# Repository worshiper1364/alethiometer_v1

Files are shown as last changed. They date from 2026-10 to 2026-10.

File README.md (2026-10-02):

# Lyra's Alethiometer

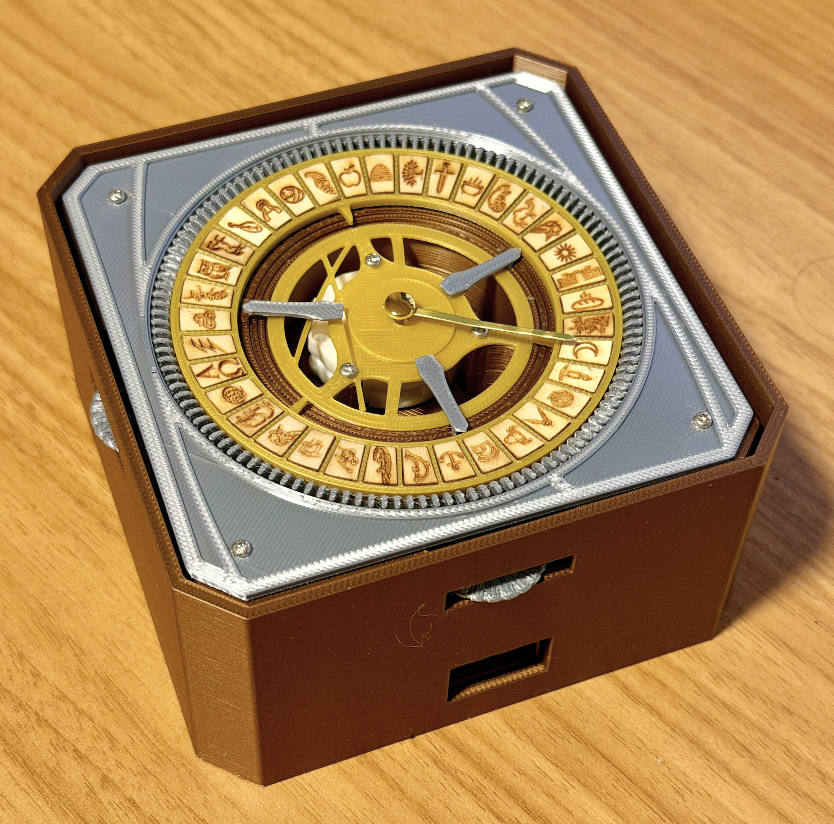
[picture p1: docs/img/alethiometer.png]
Finished alethiometer
 

https://github.com/user-attachments/assets/59460df4-214a-49e5-ad2c-306fc8ed92e8

An alethiometer is a divination device from the book series _His Dark Materials_ by Philip Pullman. This version is based on the one in [this YouTube video](https://www.youtube.com/watch?v=rpL9xWBeznU) which was created by Jamie of [Myth Made](https://www.youtube.com/@themythmade). That replica was in turn based on the prop from the BBC TV show adaptation of _His Dark Materials_.

This is an unofficial fan project and a collection of files intended to help others build an alethiometer. It is not super organized. Although I cannot guarantee any help, feel free to post questions in [r/AlethiometerBuild](https://www.reddit.com/r/AlethiometerBuild/)

## Sections
I've organized roughly by fabrication method

* [Electronics](electronics/)
* [Laser cutting](laser_cutting/)
* [3D printing](3d_printing/)

## Broad Assembly Steps

1. Print all the 3D printed parts
2. Laser engrave and cut all the symbol tiles and place them into the symbol holder
2. Drill existing holes on the motor plate to the right size
3. Drill the axle holes of the gears wider
3. With a soldering iron, install the heat set threaded inserts
2. Solder jumper wires to motor pins
3. Connect/solder wires to touch sensor module
2. Mount Nano to half size breadboard
3. Upload the Adruino sketch onto the Nano
4. Highly recommend wiring motor and touch sensor to the breadboard and testing it works before proceeding
3. Place motor plate support wall in the lower case, making sure windows line up
4. Stick the breadboard with Nano onto the floor of the case, aligning USB port with the window away from the hand dials
5. Stick the touch sensor module through the window that is on the same side as one of the hand dials, then wire up to breadboard
6. Carefully mount the motor onto the center of the motor plate, making sure the wires go through the rectangular cutouts and the motor pegs line up with the holes in the plate
7. Place the motor plate part way into the case, making sure the hand dial cutouts line up with the slots on the case. While holding, wire up the motor to the breadboard
8. Place the motor plate on top of the motor plate stand
9. Install the inner plate into the center
10. Stack the inner gears and place them around the inner ring of the motor plate
11. Install the gears, using M3 screws
12. Place the outer silver ring thing into the center of the motor plate, lining up the ledges
13. Place the symbol holder with tiles on top of the outer silver ring thing
14. Mount the outer dial face
15. Press the clock hand onto the shaft.
16. Centre the hand on the middle of a symbol
17. Plug in USB and touch the sensor.

## Misc Notes
* This project is provided as-is, without warranty of any kind. Use it at your own risk; I accept no liability for any damage or injury resulting from its use.
* This is an unofficial personal fan project, and not affiliated with the BBC, Philip Pullman, or Myth Made
* Ventilate when soldering, heat-set tips are hot, never leave the laser unattended, and small parts are unsuitable for young kids
* This build lacks a lid and is significantly taller than Jamie's version or the BBC version in order to accommodate the electronics I was able to use. The next version I intend to make it closer to the original size, and with a lid
* Due to lack of skills and access, metal parts were substituted with 3D printed parts

## Acknowledgements
* This project would not be possible without the [Myth Made alethiometer](https://www.youtube.com/watch?v=rpL9xWBeznU) built by Jamie, who made the plans publicly available [here](https://mythmade.gumroad.com/l/trhgos). They are available for free, but please consider chipping in what you can afford like I did to support her wonderful work!
* Claude by Anthropic and ChatGPT by OpenAI were generative AI tools used for tutoring, bouncing ideas around, reviewing, and generating code. All output was reviewed by me and tested on the hardware described here.

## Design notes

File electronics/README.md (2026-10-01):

# Alethiometer Electronics

The electronics and Arduino code for the divination needle of a working alethiometer replica from His Dark Materials, based on Myth Made's [YouTube build](https://www.youtube.com/watch?v=rpL9xWBeznU). The Arduino sketch (code) is adapted from Myth Made's original code. Touch the sensor and the needle swings to a random sequence of symbols, pausing and sometimes quivering on each one.

## Folder layout

```
electronics/
├── README.md                        this file: usage, wiring and theory
└── arduino_alethiometer/
    └── arduino_alethiometer.ino     the Arduino sketch
```

The `.ino` file is the Arduino code file and can be opened with any text editor. The Arduino IDE needs the sketch folder and the `.ino` file to share a name, so keep `arduino_alethiometer/arduino_alethiometer.ino` together. No extra libraries are needed.

## Hardware

### Supplies

| Part | Description | Example Link |
| --- | --- | --- |
| Breadboard (half size) | Needs to fit in the case | [Breadboard and Jumper Wire Bundle](https://www.amazon.com/BOJACK-Values-Solderless-Breadboard-Flexible/dp/B08Y59P6D1) |
| Jumper wires (male to male)| One end is stripped and soldered to the motor pins, the other plugged into the breadboard. | Included in above |
|Dupont jumper wires (male to female)| If the sensor module has headers already attached, you may not need to solder and can use these to connect to the header pins|[40 pack wires](https://www.amazon.com/SinLoon-Breadboard-Arduino-Circuit-40-Pack/dp/B08M3QLL3Q)|
| Arduino Nano microcontroller board | I used a Nano clone, not an original Arduino Nano. Mine had headers already soldered in. You will need to follow the [Elegoo instructions](https://www.elegoo.com/blogs/arduino-projects/elegoo-arduino-nano-board-ch340-usb-driver) to install the right driver on your computer for the Arduino IDE to work with it. | [Elegoo Presoldered Nano Board USB-C](https://www.amazon.com/ELEGOO-Presoldered-Compatible-Arduino-Microcontroller/dp/B0F6Y7GS4Q) |
| Motor | X27.168 automotive gauge stepper motor. For 360° movement, you will need to open the motor and cut off the small bump on the big gear that acts as an end stop. I used a razor blade to cut and scrape, and followed up with a file. Open it carefully: the parts can spring out and are easy to lose. I highly advise taking photos as you open it up and take things out, so you can reconstruct | [Adafruit x27.168 stepper motor](https://www.adafruit.com/product/2424) |
| Touch sensor | HiLetgo TTP223B capacitive touch sensor module, default momentary mode. The mode matters for the code to work; on some modules you can change it by bridging solder pads. | [HiLetgo TTP223B capacitive touch sensor module](https://www.amazon.com/HiLetgo-TTP223B-Capacitive-Digital-Raspberry/dp/B00HFQEFWQ) |
|Clock hand| For final assembly, I used a brass colored clock hand with a hub that fit through the inner plate hole and onto the motor shaft. None of the clock hands had the right length, so I used a wirecutter to cut down to length and make a point|[Paraor Set of 20 clock hands](https://www.amazon.com/dp/B0CQ2FL2MS)|

#### Notes
* You could skip the breadboard completely by soldering wires directly from the Nano to the motor and touch sensor.
* For the Elegoo Nano board, use the cable that came with it for best results. USB-C to USB-C cables didn't work for me; only USB-A to USB-C did. (Many budget USB-C boards leave out the resistors that tell a USB-C port to supply power.) I ended up connecting: computer USB-C port -> USB-C to USB-A adapter -> USB-A end of cable -> USB-C end of cable -> Nano USB-C port.
* The motor is driven directly from the Nano's pins, with no driver chip. That's fine for the X27.168, which draws roughly 20 mA per coil at 5 V. If you substitute a different gauge motor or a 3.3 V board, check its datasheet first; a motor that draws more current needs a driver chip.
* In the Arduino IDE, choose Tools > Board > Arduino Nano. If uploading to a clone fails with a "not responding" error, set Tools > Processor to "ATmega328P (Old Bootloader)".

## Pre-build Testing

1. Wire up the Arduino Nano board, x27.168 motor and touch sensor on a half-sized breadboard, as in the wiring section below. I recommend placing the Nano with its USB connector right at the edge of the breadboard, since it will eventually need to sit right against a box wall.
2. Put the supplied pointer or a piece of tape on the motor shaft, so you can see the movement.
3. Connect the Nano to your computer.
4. Open `arduino_alethiometer/arduino_alethiometer.ino` in the Arduino IDE, select the Nano board and port, and upload.
5. Touch the sensor. The needle performs a reading, and the motor coils switch off when it finishes.

## Using it

Once the dial is fitted, rest the needle on the center of any symbol before powering on. Every move is a whole number of symbols (20 motor steps each), so if the needle starts centered and the motor completes every step, every stop lands on a symbol center. Nothing checks the needle's actual position, so a skipped step, a knock or a needle slipping on its shaft will throw it off until you re-center it.

When the coils first switch on, the needle may shift slightly, up to about 1°, as the motor settles into its first step position. That's normal, and nudging it back won't stick, because the motor pulls it back to the same spot next time.

If the needle gets bumped off-center, nudge it back onto the middle of a symbol before the next reading. Turn it slowly and gently: the motor datasheet warns that knocks or sudden spins of the pointer can damage its internal gears.

## Wiring

Looking down on the motor with the shaft to the north:

| From | To Arduino Pin | Note |
| --- | --- | --- |
| Motor NE pin | D4 | one coil |
| Motor SE pin | D5 | same coil as NE |
| Motor NW pin | D6 | the other coil |
| Motor SW pin | D7 | same coil as NW |
| Touch Sensor SIG | D2 | HIGH while touched |
| Touch Sensor VCC | 5V | |
| Touch Sensor GND | GND | |

The only hard rule is that each coil's two pins go to D4/D5 or to D6/D7. Swapping the two wires within one pair just reverses the direction of rotation.

## The touch sensor

The touch sensor measures the electrical capacitance of the pad. When your finger touches the pad, the capacitance increases, and when it rises past a threshold, the sensor switches its output HIGH. When you lift your finger, the output goes back to LOW. (The TTP223B can also be set to a toggle mode, where each touch flips the output and it stays that way, but this project uses the default momentary mode.) That HIGH signal goes to the Nano. The code on the Nano runs in a loop, and if it sees the HIGH signal on any pass through the loop, it starts the needle moving.

## How the Nano drives the motor

Very simplified, the motor has a small permanent magnet and two electromagnets. The permanent magnet spins the motor shaft through a series of gears. The Arduino code directs the Nano to set four pins high or low in a repeating pattern that flips the direction of current in the electromagnets. Each flip turns their combined magnetic field a quarter turn; the permanent magnet follows it like a compass, turning the gear train, and thus the needle.

## Serial Monitor bench tools

Optional, for testing with the Nano plugged into a computer. In the Arduino IDE open Tools, then Serial Monitor, set 115200 baud and the line ending to Newline, type a letter and press Enter. Opening the Serial Monitor resets the Nano, so you'll see the startup message.

| Command | What it does |
| --- | --- |
| `r` | Run a reading, same as touching the sensor |
| `t` | Tile tour: a full turn, one tile at a time. Every stop should be centered and it should finish where it started |
| `s` | Spin test: 3 turns one way, 3 back. It should land where it started; if not, look for skipped steps, rubbing or a slipping needle |
| `b` | Backlash test: steps backwards slowly so you can estimate the gear slack. Set `BACKLASH_STEPS` in the sketch to the step number where the needle first visibly moves (erring a step high is safe) |
| `x` | Switch the coils off |
| `?` | Show the command list |

Start `t`, `s` and `b` with the needle centered on a symbol.

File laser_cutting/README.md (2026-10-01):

# Laser Cutting

Symbol tiles were engraved on and cut out of 1/16" thick basswood using an Epilog Mini 40W CO2 laser cutter. I ended up using these settings, but you will need to test your own. Never leave a laser cutter unattended.

**Engrave**

* Speed: 70% speed
* Power: 95% power

**Cut**

* Speed: 48% speed
* Power: 98% power

The tiles fit perfectly into the symbol holder pockets, so I didn't need to use any glue. They are very hard to take out.

**`alethiometer_tiles_bold_and_standard.svg`**: This file contains two sets of symbols, one in bold and one not bold

**`alethiometer_tiles_material_test_subset.svg`**: This file contains a subset of symbols for testing

The symbols were generated with ChatGPT using written descriptions of the symbols.

## Symbol Order

Some places to find the order of symbols

* [V&A Museum Online Collection](https://collections.vam.ac.uk/item/O1779677/the-alethiometer-property-collins-joel/):  Nice high resolution photos of the alethiometer from the BBC show
* [HDM Wiki](https://hisdarkmaterials.fandom.com/wiki/Alethiometer)
* [Myth Made YouTube video](https://www.youtube.com/watch?v=rpL9xWBeznU)

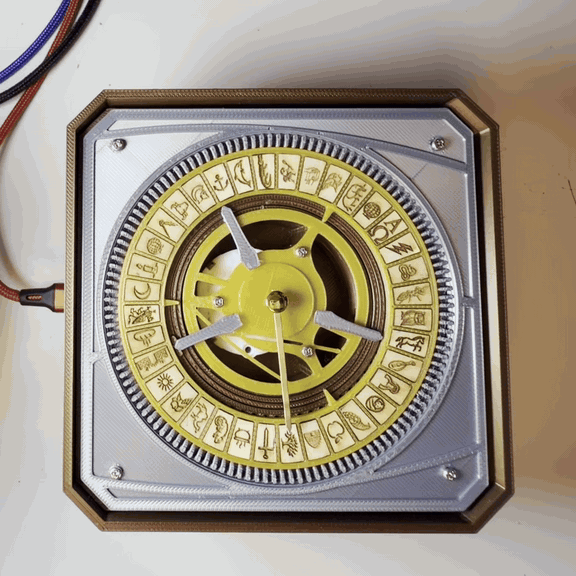
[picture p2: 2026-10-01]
docs/img/alethiometer_movement.gif

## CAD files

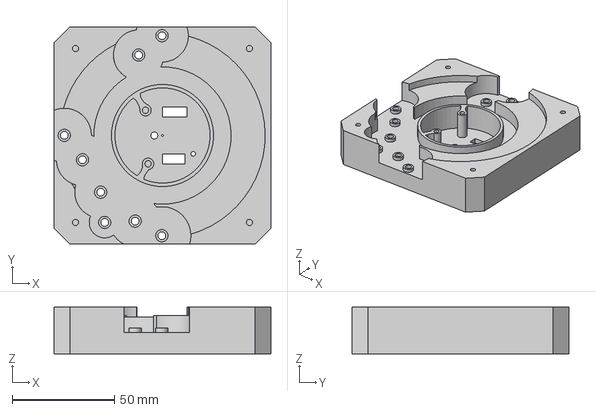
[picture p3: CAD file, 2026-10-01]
3d_printing/Motor Plate.step
105.9 x 105.9 x 22.8 mm

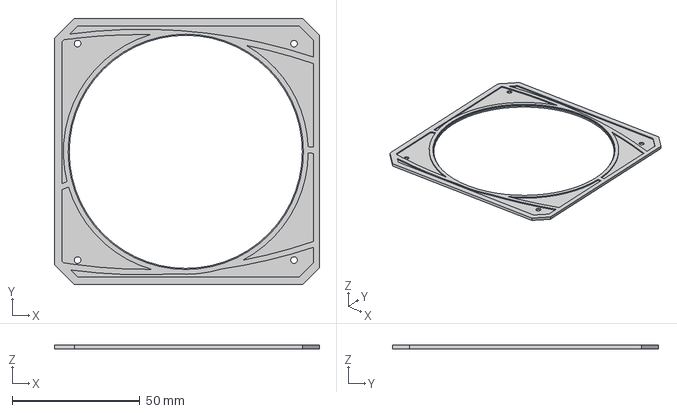
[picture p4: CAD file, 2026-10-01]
3d_printing/Outer Dial Face.step
103.9 x 104.3 x 1.40 mm

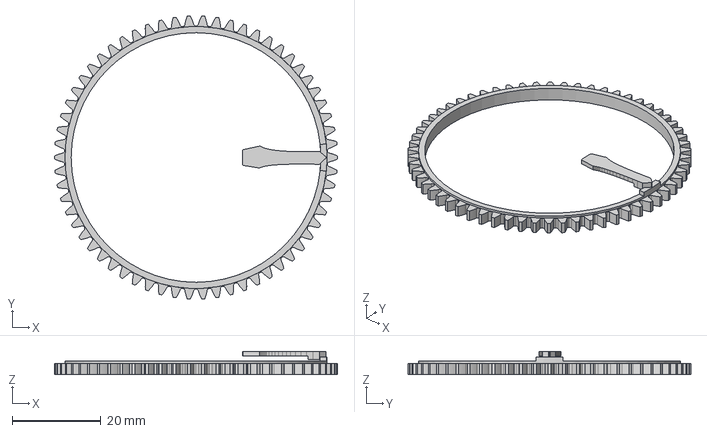
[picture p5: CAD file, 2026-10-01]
3d_printing/INN-T3.step
64.0 x 63.9 x 5.20 mm

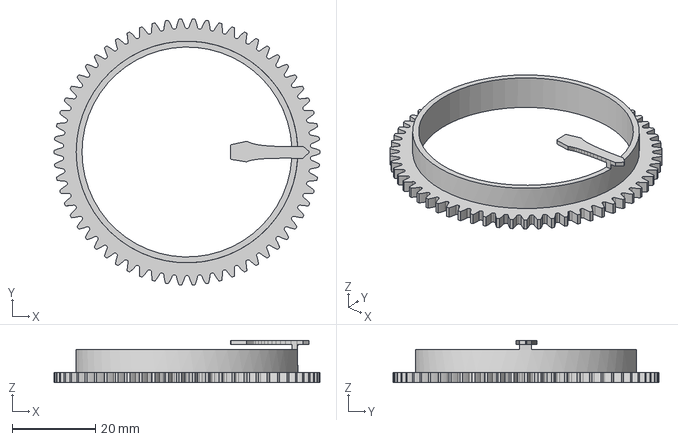
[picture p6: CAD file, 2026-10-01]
3d_printing/INN-T1.step
64.0 x 63.9 x 10.2 mm

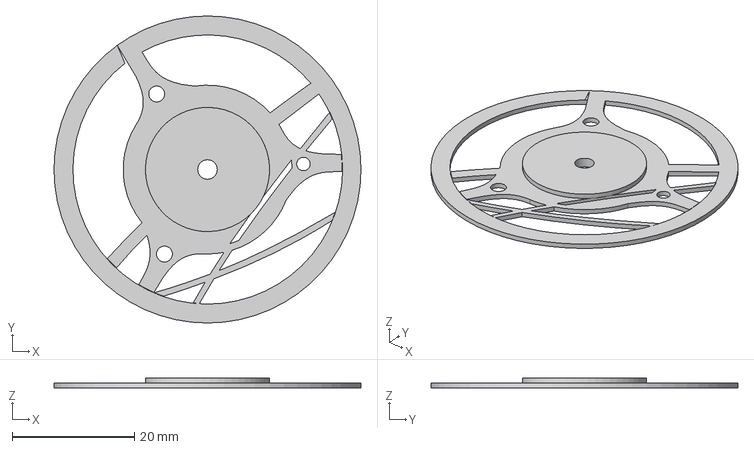
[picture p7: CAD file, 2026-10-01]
3d_printing/Inner Plate.step
50.2 x 50.2 x 1.60 mm

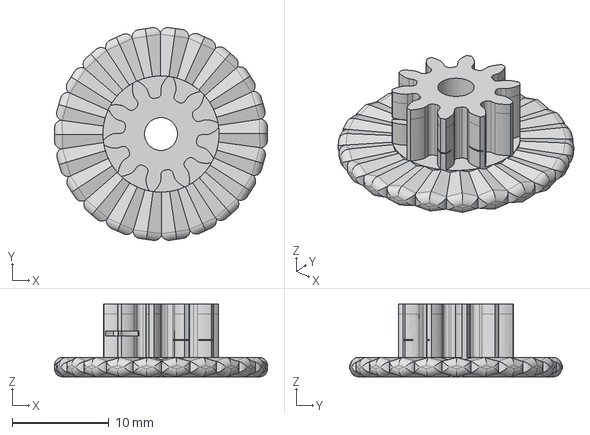
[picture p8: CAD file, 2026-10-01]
3d_printing/Hand Dial.step
22.0 x 22.0 x 7.50 mm

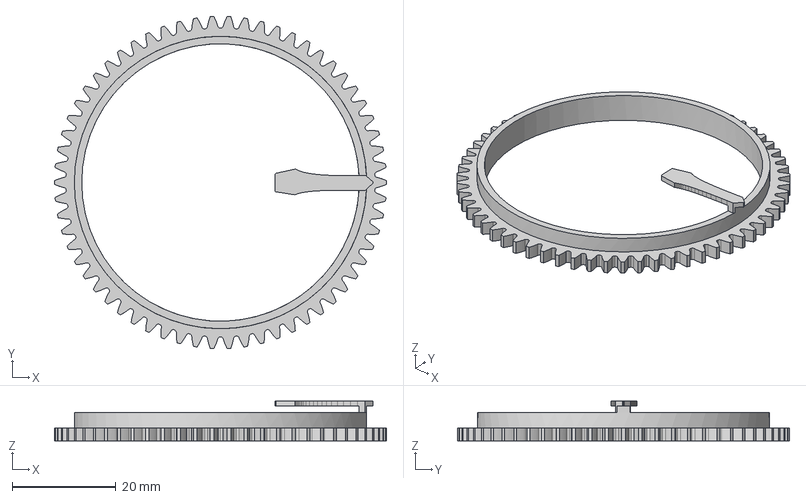
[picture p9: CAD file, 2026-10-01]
3d_printing/INN-T2.step
64.0 x 63.9 x 7.70 mm

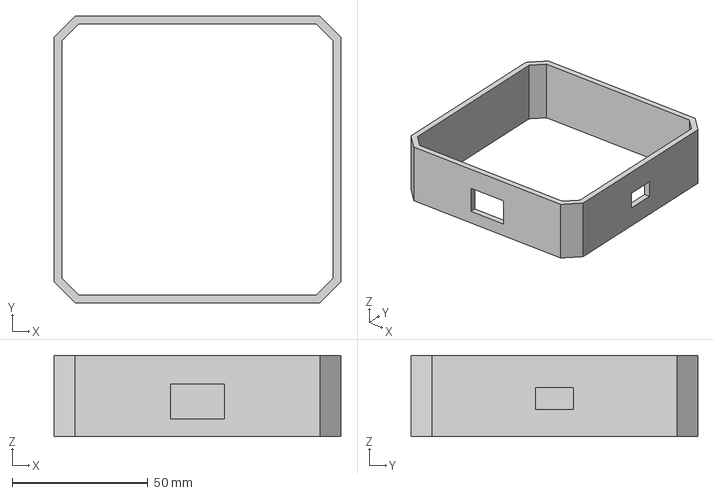
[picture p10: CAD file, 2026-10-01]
3d_printing/Motor Plate Support Wall.step
105.9 x 105.9 x 30.0 mm

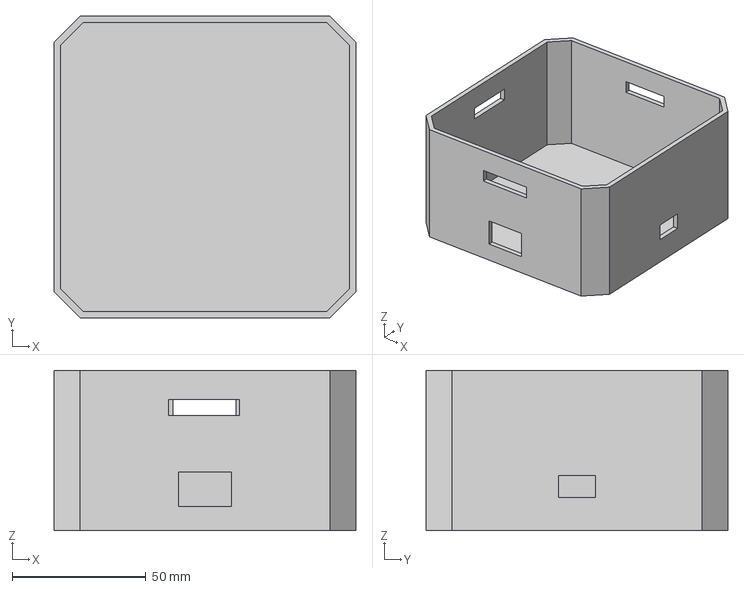
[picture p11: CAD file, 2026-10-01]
3d_printing/lower_case.step
112.9 x 112.9 x 60.0 mm

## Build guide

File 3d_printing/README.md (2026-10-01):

# 3D Printing

Unless otherwise specified, parts were printed on a Bambu A1 Mini using the `0.20mm Standard @BBL A1M` preset, or modifications of that preset.

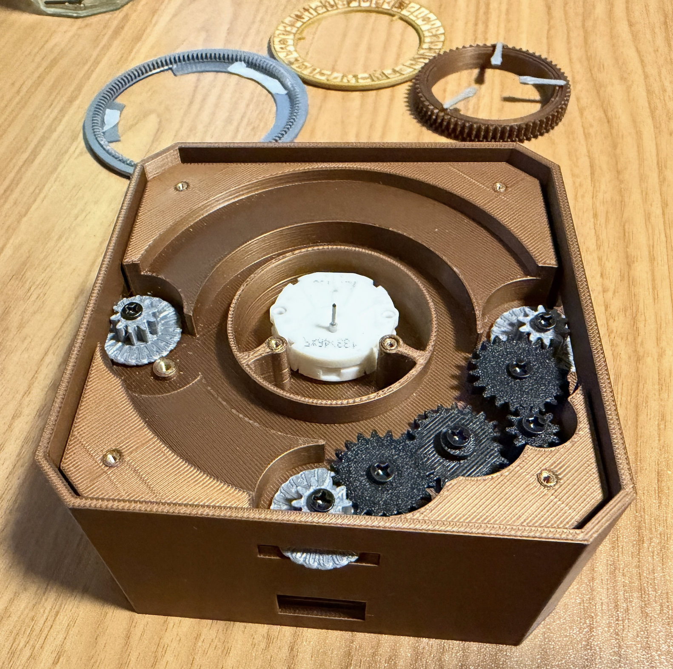
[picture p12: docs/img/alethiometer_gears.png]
Finished alethiometer


## Filaments

For the following profiles, I changed it in Bambu Studio; your slicer may vary. Always check the labeling on the actual filament spool or package to confirm that the settings sense.

|Short Name|Manufacturer|Name|Print Profile|Notes|
|:--- |:--- |:--- |:--- |:--- |
|Gold|Sunlu|[PLA Plus Gold](https://www.amazon.com/dp/B0CJLT7Z9M)|*Sunlu PLA+*  preset already in Bambu Studio |Not really like gold or brass but is any filament?
|Silver|Elegoo|[PLA Silk Silver Grey](https://www.amazon.com/dp/B0C6QFDQWT)| See below
|Copper|Elegoo|[PLA Metal Bronze](https://www.amazon.com/dp/B0DFPKMPHB)|See below|Says bronze in listing, but what I got says copper filled|
|Black|?|Black ABS||These were sent off to a service to print, but PLA or PETG on a home printer should probably be fine|

### Copper filament profile

Bambu Studio export in this folder as `ELEGOO PLA Copper 1-2606-0619.bbsflmt` and is specific to Specific to Bambu Lab A1 mini 0.4 nozzle. Or you can follow these steps

1. Create new profile based on Generic PLA in the filament dropdown
2. Change these values:
	*  Nozzle: 215°C first layer, 210°C other layers
	*  Bed: 55°C (textured PEI)
	*  Max volumetric speed: 8 mm³/s. This is the key one for metal-filled PLA, which flows worse than plain PLA.

### Silver filament profile

Bambu Studio  export in this folder as `ELEGOO PLA Silk Silver Grey 1-2606-0612.bbsflmt` and is specific to Specific to Bambu Lab A1 mini 0.4 nozzle. Or you can follow these steps

1. Create new profile based on Generic PLA Silk
2. Change these values:
	* Nozzle: 225°C first layer, 220°C other layers
	* Bed: 55°C
	* Max volumetric speed: 7.5 mm³/s
	* Retraction -> Length: 0.5mm

## Myth Made Models

The items below were printed unmodified from the Myth Made CAD model. You can get them and Jamie's other alethiometer plans [here](https://mythmade.gumroad.com/l/trhgos). They are available for free, but please consider chipping in what you can afford like I did to support her wonderful work! This build would not be possible without her.

You will need to import the `.f3z` into [Autodesk Fusion](https://www.autodesk.com/products/fusion-360/personal), which is free for personal use. From there, you can right click on a specific component, and export to `.step` or Save As mesh to .stl or .3mf. Be sure to use High refinement if you are exporting to `.stl` or `.3mf`. If the part in question is a body and not a component, you will need to right click on the body and convert it into a component first.

|Name in model| Description| Filament |Notes|
|:--- |:--- |:--- |:--- |
|symbol holder|Holds the symbol tiles|Gold | Supports on base plate only|
|outer silver ring thing|Sits on top of the motor plate and holds the symbol holder|Silver | Supports on base plate only|
|Gears -> Middle Gear||Black||
|Gears -> Bodies -> Body11||Black||
|Gears -> Bodies -> Body1||Black||
|Gears -> Left gear||Black||
|Gears -> Middle Gear||Black||
|Gears -> Bodies -> Body2||Black||

### Drilling
Any gears above should have their axle hole drilled out to 3.5mm so it will spin freely on a M3 screw

## Models in this Repository

These models are a mix of new creations and modifications of models from Myth Made. `.step` files are in this directory and can be imported by slicers for printing or CAD programs to modify

If there is a `.py` file with the same name as a CAD file, that `.py` contains Fusion API python code that when run as a script in Fusion, creates the model. This parametric code is hypothetically easier for LLMs to work with and allows for easier modification via parameter changes. Fusion API functions are black boxes, but having the python code gives some clues as to how to recreate the model.

## lower_case

### Description

This is the outer case of the alethiometer in which everything lives. There is no upper case for this build. This case contains a window cutout for the touch sensor, and a cutout for plugging a USB cable to the Nano. There are also narrower slit cutouts for the three hand dials used to turn the gears inside. The gear train will move the three set pointers. 

### Printing

Default Bambu Studio settings for the Bambu A1 mini were used except for below

* **Filament:** Copper
* **Supports:** Off

### Assembly Notes
You will want to wait until you have the motor plate support wall before you do anything

## Motor Plate Support wall

### Description
This is a wall that fits inside the lower case. The wall runs along the inside of the lower case and designed to prop up the motor plate above the electronics below. This case contains a window cutout for the touch sensor, and a cutout for plugging a USB cable to the Nano. These cutouts should match the equivalent from the lower case.

### Printing

Default Bambu Studio settings for the Bambu A1 mini were used except for below

* **Filament:** Copper
* **Supports:** Off

Since this is not seen from the outside, any color or material should do

### Assembly Notes

1. Place this inside the lower case before you attach anything to the case.
2.  Make sure the windows line up. 
3. Plug the Nano into the half size breadboard so that the USB port is on the very outside edge. 
4. Note: There is a sticker you can peel off under the breadobard to reveal some glue that will hold the breadboard in place. 
5. The USB-port window is on the side with no hand wheel cutout. 
6. Place the breadboard with Nano onto the bottom of the lower case, with the USB port facing this window.

For the touch sensor, I used blu-tack to stick it against the touch sensor window and hold it in place. The touch sensor board has screw holes also that you can probably use if you want to drill through the motor plate support wall and/or lower case.

## Motor Plate
### Description
The motor plate holds the x27.168 motor and requires some modification after printing (see Assembly below). It will hold the motor, the gears, and dial faces.

### Printing

Default Bambu Studio settings for the Bambu A1 mini were used except for below

* **Filament:** Copper
* **Supports:** Off

### Assembly Notes

#### Drilling
Because 3D printed holes can be off in size, they were deliberately printed smaller than actual, so that the correct size could be made using a drill bit. I used a hand held manual pin vise drill for all of the below.

##### Motor
These are the two rectangular cutouts inside the inner circular wall near the center of the plate. These are intended for the wires of the x27.168 motor to go through to the bottom and plug into the breadboard.

There are also two circular holes that serve to hold the motor in place. The two pegs on the x27.168 slot into these. These need to be drilled out before use. The smaller hole should be drilled to a diameter of **2.5 mm**, and the larger hole is **3.8 mm**.

##### Axle Holes
There are 8 holes at the very bottom of the motor plate, outside of the circular wall, that serve as the holes for inserting a heat set screw thread. The screw threads will hold a screw that serves as the axle for the gears. These holes have a raised rim around them. I drilled these open to **4 mm**, but it might depend on which heat set inserts you use (see below).

##### Dial face fasteners
There are two "peninsulas" with holes inside the inner ring, and four holes closer to the outer, higher areas of the motor plate. These are intended for heat set screw thread inserts that will hold screws that fasten the dial faces onto the motor plate.

I did NOT drill them out further.

#### Heat Set Screw Thread Inserts

Heat set threaded inserts are designed so that you can

1. Place the heat set insert the right way into the hole
2. Use soldering iron with an adapter and special tip to heat the insert, which melts/softens the plastic and allows you to push down and put the insert into place

Most of the holes need to have a screw thread in order for the screws serving as the fasteners and axles to stay in place. I bought variety packs in M2 and M3, meaning each pack had a variety of thread insert lengths.

Here are some examples of Heat Set Inserts, ideally you should get one that comes with a soldering iron tip that fits the inserts:

* [Nefuree Threaded Inserts for Plastic, Heat Set, sizes M2 through M6 with tips and adapter](https://www.amazon.com/dp/B0GYD133M5)
* [Kadrick Heat Set Inserts Kit, M3, with tip](https://www.amazon.com/dp/B0FD88XTV4)
* [Ruthex M2x4 Threaded Inserts](https://www.amazon.com/dp/B088QJG676)
* [Ruthex Soldering Iron Tips](https://www.amazon.com/dp/B0DP51DDF7)

#### Axle Holes
Use M3 threaded inserts

#### Dial Face Fasteners
Use M2 threaded inserts

## Inner Gears, with integrated set pointer
These are three separate files, named
* `INN-T1.step`
* `INN-T2.step`
* `INN-T3.step`

These are the stacking inner gears that go around the inner ring of the motor plate. In the Myth Made build, a cut piece of flat wire was heated, then inserted into a groove on the inner gear. Then a CNC'd metal pointer was glued on top of that. 

I had a lot of trouble doing this, and ended up with deformed gears, or the flat wire just came off after it got attached. I also don't have access to a CNC. So I decided to go a different way, to print the set pointers directly attached to the inner gears.

### Printing

Default Bambu Studio settings for the Bambu A1 mini were used except for below

* **Filament:** First copper, then a pause as added in the slicer right before the set pointer, so you can switch the filament to switch to silver. You may not need this if you can print in multiple colors already.
* **Supports:** On, base support only

The connection between the gear and the set pointer is very thin and fragile, so you have to take great care when handling to not break them off. This print also require supports for the set pointer. 

I recommend when taking the gears off the plate, to first carefully scrape the supports off before taking off the entire gear. I recommend when taking off the supports, to put the gear upside down and pushing down on the gear ring so the thin connector is held in place and not pulled upon, and pulling the supports away from the ring towards the center

### Assembly Notes

1. Stack all the inner gears together BEFORE placing it in the motor plate.
2. Each set pointer is restricted to its own third circle on the dial face by the symbol holder, which is just as well, because the set pointers on these inner gears cannot slide by each other. Attempting to do so may break off the set pointers.

## Hand Dial
### Description
The three hand dials stick out of the motor plate in the cutouts. Turning these will turn the gears attached and turn the inner gear, which will move the set pointer around to the symbol of your choice. These are modified from Myth Made to make the divot on the bottom of the hand dial deeper, because I found the hand dial needed to seat lower for clearance.

### Printing

Default Bambu Studio settings for the Bambu A1 mini were used except for below

* **Filament:** Silver
* **Supports:** On, base support only

You might not need supports. If you use supports, you will need to tear out the supports at the bottom center of the hand dial. I used fine tweezers to do so.

### Drilling
As with all the gears, drill out the center hole with a **3.5 mm** diameter drill bit to so that it will spin freely around the screw without catching.

### Assembling
Hand dials are placed on the outermost gear positions. As with the other gears, you will need to use an M3 screw to serve as an axle for the gear to turn around. The head type is flat and counter sunk because it needs to seat low for proper clearance for other parts.

## Inner Plate
### Description
The inner plate in Myth Made consisted of two brass plates. I switched to 3D printing due to lack of CNC access. The inner plate here consists of one piece

### Printing

Default Bambu Studio settings for the Bambu A1 mini were used except for below

* **Filament:** Gold
* **Supports:** Off

### Assembling
Use silver colored M2 screws to screw to the "peninsula" thread inserts. Two of the screw holes are one size, and a third is different. You may have to trial and error rotate so that the screw holes line up with the peninsula.

This should be placed after the motor is in place, but before inner gears are installed

## Outer Dial Face

### Description
The outer dial face in Myth Made consisted of two aluminum plates, and is much more intricate. I switched to 3D printing a simpler face due to lack of CNC access.

### Printing

Default Bambu Studio settings for the Bambu A1 mini were used except for below

* **Filament:** Silver
* **Supports:** Off

### Assembling
This should be the second to last last item installed on the alethiometer. Screw into holes using silver colored M2 screws

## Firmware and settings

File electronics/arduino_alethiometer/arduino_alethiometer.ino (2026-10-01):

/*
 * =====================================================================================
 *  arduino_alethiometer.ino
 *
 *  Purpose: Drives the divination needle of an alethiometer. An Arduino Nano (or similar
 *  clone) turns an X27.168 stepper motor whose internal end-stop has been cut out so it
 *  can spin a full 360 deg. Adapted from Myth Made's original alethiometer sketch.
 *
 *  Before powering on, rest the needle on the center of any symbol.
 *
 *  How it works: touching the sensor starts a "reading". The needle swings a random
 *  number of symbols one way or the other, pauses, sometimes quivers, and repeats 2 to 6
 *  times. Every swing is a whole number of symbols (20 motor steps each), so if the
 *  needle starts centered on a symbol and the motor completes every step, it stops on a
 *  symbol center. Nothing checks this (open-loop control), so a skipped step, a
 *  knock or a needle slipping on its shaft will throw it off until it's re-centered.
 *
 * =====================================================================================
 */


// =====================================================================================
// 1. HARDWARE: pins and the step pattern table
// =====================================================================================

// The four motor wires. D4 and D5 connect to one coil (electromagnet), D6 and D7 to the
// other. See README "Wiring".
// The motor is driven straight from these pins, with no driver chip.
const uint8_t motorPins[4] = {4, 5, 6, 7};
const uint8_t buttonPin    = 2;          // touch sensor output: HIGH while touched

// The pin patterns that turn the motor, one row per step. Each row sets D4, D5, D6, D7
// high (1) or low (0). Moving down the table turns the motor one way, moving up turns it
// the other way, and after row 3 it wraps back to row 0. From one row to the next, the
// current flips direction in just one coil. README "How the Nano drives the motor"
// explains why that makes the motor turn
// (In the notes below, + and - are the two directions of current through a coil.)
const uint8_t stepSequence[4][4] = {
  {1, 0, 0, 1},   // row 0: coil 1 +, coil 2 -
  {1, 0, 1, 0},   // row 1: coil 1 +, coil 2 +
  {0, 1, 1, 0},   // row 2: coil 1 -, coil 2 +
  {0, 1, 0, 1}    // row 3: coil 1 -, coil 2 -
};


// =====================================================================================
// 2. GEOMETRY: steps, degrees and symbols
// =====================================================================================

// The motor's internal gears turn each step into half a degree at the needle.
const int   STEPS_PER_REV  = 720;                       // steps per full turn of the needle
const int   NUM_TILES      = 36;                        // symbols on the dial
const int   STEPS_PER_TILE = STEPS_PER_REV / NUM_TILES; // 20 steps = 10 deg per symbol
const float DEG_PER_STEP   = 360.0 / STEPS_PER_REV;     // 0.5 deg


// =====================================================================================
// 3. FEEL: numbers you can tune to change how the needle moves
// =====================================================================================

const float PEAK_SPEED_DEG_S      = 110.0; // top speed mid-swing. The motor can start and stop
                                           // instantly only below about 250 deg/s, so stay well under
const unsigned long MIN_SWING_MS  = 750;   // even short hops take this long, so they glide
const int   MIN_HOP_TILES         = 3;     // shortest swing: 3 symbols = 30 deg
const int   MAX_HOP_TILES         = 18;    // longest swing: 18 symbols = 180 deg, never the long way round
const int   REVERSE_PERCENT       = 70;    // chance each new swing reverses direction
const unsigned long PAUSE_MIN_MS  = 1500;  // pause on each symbol, chosen at random
const unsigned long PAUSE_MAX_MS  = 3000;  //   between these two values
const int   QUIVER_STEPS          = 6;     // visible quiver size: 6 steps = 3 deg
const unsigned long QUIVER_MS     = 130;   // duration of each half of one quiver
const unsigned long MIN_STEP_US   = 1500;  // safety limit: never step faster than this
                                           // (1 step per 1.5 ms = 667 steps/s = 333 deg/s)


// =====================================================================================
// 4. GEAR SLACK
// =====================================================================================

// Gears have a little play between their teeth, so when the motor changes direction the
// needle lags very slightly. To land in the same spot every time, every stop
// finishes with a forward (+) move: forward swings already arrive that way, and backward
// swings go slightly past and then settle forward. This only covers slack up to
// BACKLASH_STEPS + TAKEUP_MARGIN_STEPS; it can't fix more slack than that, or a needle
// slipping on its shaft.
const int   BACKLASH_STEPS        = 1;     // rough estimate from the 'b' test (1 step = 0.5 deg)
const int   TAKEUP_MARGIN_STEPS   = 4;     // extra overshoot beyond the slack on backward moves
const unsigned long SETTLE_MS     = 350;   // time for the small settle back onto a symbol


// =====================================================================================
// 5. MOTOR STATE
// =====================================================================================

uint8_t phase   = 0;       // which row of stepSequence is being output (0 to 3)
bool    coilsOn = false;   // are the coils currently powered?


// =====================================================================================
// 6. MOTOR DRIVE: the only code that writes to the motor pins
// =====================================================================================

// Output the current row's pattern. Each coil is wired between two pins: one high and
// one low pushes current through it one way, and swapping them pushes it the other way.
// If the coils were off, pause 30 ms so the motor's magnet can settle into position
// before stepping. That settling can shift a hand-placed needle slightly. The motor has
// one magnetic "notch" for each 2 deg of needle travel, so the shift should be at most
// about 1 deg, plus a little gear slack. Nudging the needle back by hand won't stick:
// the motor pulls it to the same notch next time the coils switch on.
void energise() {
  const uint8_t *pattern = stepSequence[phase];
  for (uint8_t i = 0; i < 4; i++) digitalWrite(motorPins[i], pattern[i]);
  if (!coilsOn) { coilsOn = true; delay(30); }
}

// Set all four pins low: no current in either coil, so nothing heats up. The motor no
// longer actively holds its position. Friction in the gears and the magnet's pull on
// the motor's steel usually keep the needle still, but a knock can move it.
void release() {
  for (uint8_t i = 0; i < 4; i++) digitalWrite(motorPins[i], LOW);
  coilsOn = false;
}

// Take one step forward (dir = +1) or backward (dir = -1): move to the next or previous
// row and output it. "& 3" wraps the row number round, so after row 3 comes row 0 and
// before row 0 comes row 3. (It keeps only the last two binary digits of the number.)
void stepOnce(int dir) {
  phase = (phase + dir) & 3;
  energise();
}

// Work out how long a swing should take so its top speed is PEAK_SPEED_DEG_S. A smooth
// S-curve move reaches twice its average speed at the midpoint, so
// time = 2 x distance / top speed. (The 2000 is 2 x 1000 milliseconds per second.)
// Short hops are stretched to MIN_SWING_MS.
unsigned long swingMs(long steps) {
  float deg = labs(steps) * DEG_PER_STEP;
  unsigned long ms = (unsigned long)(2000.0 * deg / PEAK_SPEED_DEG_S);
  return (ms < MIN_SWING_MS) ? MIN_SWING_MS : ms;
}

// Move 'delta' steps (positive one way, negative the other) over 'durationMs': start
// slowly, speed up, then slow to a gentle stop. This uses a smooth sine-based
// profile (known as a cycloidal profile); plotted as position against time it makes an
// S shape, hence "S-curve". A sudden start could make the motor skip steps, and nothing
// would notice, because the code never checks where the needle really is; it just
// counts the steps it sends.
//
// Instead of pausing a fixed time between steps, the loop keeps checking the clock and
// asks "how many steps should be done by now?", taking a step whenever it's behind,
// but never faster than MIN_STEP_US. With the default settings, steps are always at
// least about 4 ms apart, so that limit never kicks in. If you raise the speeds enough
// to hit it, the needle lags behind the curve and catches up, so moves get slightly
// longer than planned.
void sCurveMove(long delta, unsigned long durationMs) {
  if (delta == 0) return;
  int  dir   = (delta > 0) ? 1 : -1;
  long total = labs(delta);              // number of steps to take
  energise();                            // make sure the coils are on

  float T = durationMs * 1000.0;         // duration in microseconds
  // micros() counts microseconds since power-up and wraps back to zero about every
  // 70 minutes. Subtracting unsigned numbers ("now - t0") still gives the right answer
  // when that happens, which is why these are unsigned long.
  unsigned long t0 = micros();
  unsigned long lastStep = t0 - MIN_STEP_US;   // allows a first step straight away
  long done = 0;

  while (done < total) {
    unsigned long now = micros();
    float u = (now - t0) / T;            // fraction of the move's time used so far, 0 to 1
    if (u > 1.0) u = 1.0;
    // The S-curve: fraction of steps done = u - sin(2 pi u) / (2 pi), scaled up to steps
    // and rounded (the + 0.5). The Nano has no hardware for decimal maths, so this is
    // worked out in software, but it's still quick compared with the gap between steps.
    long want = (long)(total * (u - sin(TWO_PI * u) / TWO_PI) + 0.5);
    // Step if behind the curve, but never faster than the safety limit.
    if (want > done && (now - lastStep) >= MIN_STEP_US) {
      stepOnce(dir);
      done++;
      lastStep = now;
    }
  }
  delay(20);  // let the final step physically finish before anything else happens
}

// Move by 'delta', always finishing with a forward move (see section 4). A forward move
// goes straight there. A backward move goes slightly past the target, pauses, then
// settles forward onto it.
void settleMove(long delta, unsigned long durationMs) {
  if (delta >= 0) { sCurveMove(delta, durationMs); return; }
  long extra = BACKLASH_STEPS + TAKEUP_MARGIN_STEPS;
  sCurveMove(delta - extra, durationMs);
  delay(120);
  sCurveMove(extra, SETTLE_MS);
}

// Swing a whole number of symbols: positive one way, negative the other. Keeping every
// move a whole number of symbols is what keeps a hand-centered needle landing on symbol
// centers, as long as the motor doesn't miss steps (README "Using it").
void swingTiles(int tiles) {
  long delta = (long)tiles * STEPS_PER_TILE;
  settleMove(delta, swingMs(delta));
}

// One small tremble on the current symbol: back a little, then forward onto it again.
// The backward part is enlarged by the gear slack so the visible size stays
// QUIVER_STEPS, and it finishes with a forward move so the needle lands exactly where it
// began.
void quiver() {
  long a = QUIVER_STEPS + BACKLASH_STEPS;
  sCurveMove(-a, QUIVER_MS);
  sCurveMove( a, QUIVER_MS);
}


// =====================================================================================
// 7. DIVINATION: choosing and performing a reading
// =====================================================================================

// How many symbols this reading visits. random(1, 101) picks a whole number from 1 to
// 100. Checking it against rising cut-offs gives each outcome a slice of 1..100 as wide
// as its chance of happening. Weights from Myth Made's original sketch.
int pickNumberOfSymbols() {
  int r = random(1, 101);
  if (r == 1)  return 6;     // 1%
  if (r <= 10) return 5;     // 9%
  if (r <= 24) return 4;     // 14%
  if (r <= 50) return 2;     // 26%
  return 3;                  // 50%
}

// How many quivers at a stop (same technique, using 0..99).
int pickQuivers() {
  int r = random(100);
  if (r < 45) return 0;      // 45%
  if (r < 75) return 1;      // 30%
  if (r < 92) return 2;      // 17%
  return 3;                  // 8%
}

// A full reading: several swings of random length, with pauses and quivers.
void divination() {
  int n   = pickNumberOfSymbols();
  int dir = random(2) ? 1 : -1;          // first swing: either direction, 50/50
  Serial.print(F("Reading, ")); Serial.print(n); Serial.println(F(" symbols:"));

  for (int i = 0; i < n; i++) {
    // After the first swing, usually reverse, so the needle swings back and forth rather
    // than circling like a clock hand.
    if (i > 0 && random(100) < REVERSE_PERCENT) dir = -dir;
    int hop = random(MIN_HOP_TILES, MAX_HOP_TILES + 1);   // how many symbols to travel
    swingTiles(dir * hop);

    int q = pickQuivers();
    for (int k = 0; k < q; k++) { delay(250); quiver(); }

    Serial.print(F("  swing ")); if (dir > 0) Serial.print('+'); Serial.print(dir * hop);
    Serial.print(F(" tiles, quivers ")); Serial.println(q);

    if (i < n - 1) delay(random(PAUSE_MIN_MS, PAUSE_MAX_MS + 1));  // pause (not after the last)
  }
  release();                             // coils off until next time
}


// =====================================================================================
// 8. BENCH TOOLS: Serial Monitor test commands (see README "Serial Monitor bench tools")
// =====================================================================================
// F("...") stores text in the Nano's program memory instead of its small 2 KB working
// memory.

void printHelp() {
  Serial.println(F("Commands: r (reading)  t (tile tour)  s (spin test)  b (backlash test)  x (coils off)  ? (help)"));
}

// A full turn, one symbol at a time, finishing on the starting symbol.
void tileTour() {
  Serial.println(F("Tile tour: every stop should be centered."));
  for (int k = 1; k <= NUM_TILES; k++) {
    swingTiles(1);
    Serial.print(F("  tile ")); Serial.println(k);
    delay(400);
  }
  Serial.println(F("Tour done. Needle should be back where it started, dead center."));
}

// Three full turns one way, then three back. If the needle doesn't return to where it
// started, look for skipped steps, something rubbing, or the needle slipping on its
// shaft. Passing is a good sign, but it doesn't prove every move is perfect.
void spinTest() {
  Serial.println(F("Spin test: 3 turns one way, 3 back..."));
  sCurveMove( 3L * STEPS_PER_REV, swingMs(3L * STEPS_PER_REV));
  delay(800);
  settleMove(-3L * STEPS_PER_REV, swingMs(3L * STEPS_PER_REV));
  Serial.println(F("Done. Needle should be back where it started. If not, look for skipped steps, rubbing or a slipping needle."));
}

// Estimate the gear slack. The quiver leaves the gears pressed forward; then the
// motor steps backward slowly and you note the step where the needle first visibly
// moves. How closely you can see that varies, so treat the result as a rough estimate;
// erring a step high is safe.
void backlashTest() {
  quiver();
  delay(1000);
  Serial.println(F("Backlash test: the motor steps backwards once every 0.8 s."));
  Serial.println(F("Watch the needle tip. Note the step number where it FIRST visibly moves."));
  for (int k = 1; k <= 20; k++) {
    stepOnce(-1);
    Serial.print(F("  step ")); Serial.println(k);
    delay(800);
  }
  sCurveMove(20, 800);   // straight back, finishing with a forward move
  Serial.println(F("Set BACKLASH_STEPS to that number, upload, done."));
}

// Read any characters typed into the Serial Monitor and act on each one.
void handleSerial() {
  while (Serial.available()) {
    char c = Serial.read();
    switch (c) {
      case 'r': case 'R': divination();   break;
      case 't': case 'T': tileTour();     break;
      case 's': case 'S': spinTest();     break;
      case 'b': case 'B': backlashTest(); break;
      case 'x': case 'X': release(); Serial.println(F("Coils off.")); break;
      case '?':           printHelp();    break;
      default: break;   // ignore newlines, spaces, etc.
    }
  }
}


// =====================================================================================
// 9. SETUP AND LOOP
// =====================================================================================

// Runs once at power-up or reset.
void setup() {
  // Motor pins become outputs, starting low so both coils begin switched off.
  for (uint8_t i = 0; i < 4; i++) {
    pinMode(motorPins[i], OUTPUT);
    digitalWrite(motorPins[i], LOW);
  }
  // The touch sensor sets its own output high or low, so a plain input is enough.
  pinMode(buttonPin, INPUT);
  Serial.begin(115200);

  // random() isn't truly random: it follows a fixed sequence that depends on a starting
  // "seed". Reading an unconnected pin gives a rough seed from electrical noise, and
  // the timing of the first touch is mixed in later (see loop).
  randomSeed(analogRead(A0));

  Serial.println(F("Alethiometer ready. Needle should be resting on the center of a symbol."));
  printHelp();
}

// Runs over and over, forever. Each pass checks for Serial commands and whether the
// touch sensor is HIGH (see README "The touch sensor").
void loop() {
  handleSerial();

  if (digitalRead(buttonPin) == HIGH) {
    // A "static" variable keeps its value between passes of loop(). On the first touch,
    // mix the exact microsecond of the touch into the seed. That makes the readings very
    // likely to differ each time the alethiometer is switched on, though it can't
    // guarantee it.
    static bool seeded = false;
    if (!seeded) { randomSeed(micros() ^ random(0x7FFFFFFFL)); seeded = true; }

    divination();
    delay(500);  // still touching after the reading? Then another reading starts.
  }
}

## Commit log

2026-10-01 add the files
    [Hand Dial.step, INN-T1.step, INN-T2.step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]
2026-10-01 added gears image
